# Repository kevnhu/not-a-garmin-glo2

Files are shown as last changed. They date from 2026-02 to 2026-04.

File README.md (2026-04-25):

# ForeFlight WiFi GPS

A WiFi GPS receiver for ForeFlight using ESP32, M8N GPS module, and OLED display. Built with ESP-IDF framework in pure C with FreeRTOS.

The ESP32 creates a WiFi access point and sends GPS data to ForeFlight using the GDL90 protocol over UDP. Just connect your iPad to the "ForeFlight GPS" WiFi network and ForeFlight automatically picks up the GPS data - no pairing or certification needed.

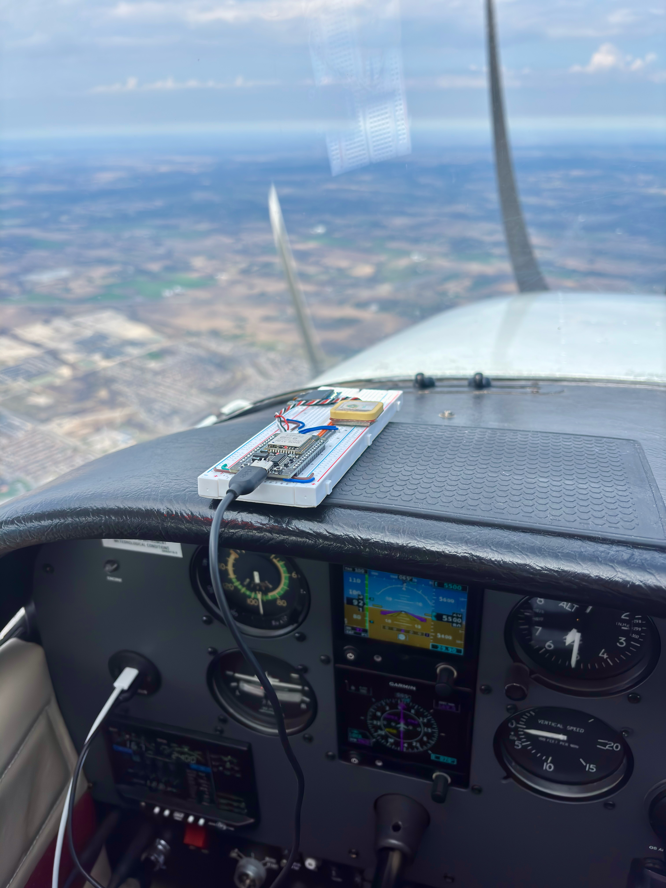
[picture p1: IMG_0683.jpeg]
ForeFlight GPS in use on a flight to Billy Bishop (CYTZ)


## Hardware Requirements

- ESP32 development board
- M8N GPS module (u-blox, 115200 baud, UBX protocol)
- 128x64 OLED display (I2C, SSD1306)
- Jumper wires
- USB cable for programming
- Battery/power source (optional, for portable use)

## Wiring Connections

### M8N GPS Module
- **GPS TX** → ESP32 **GPIO16** (RX2)
- **GPS RX** → ESP32 **GPIO17** (TX2)
- **VCC** → ESP32 **5V** pin (passes USB voltage through)
- **GND** → **GND**

### OLED Display (I2C)
- **SDA** → ESP32 **GPIO21**
- **SCL** (also labeled SCK on some modules) → ESP32 **GPIO22**
- **VCC** → ESP32 **3.3V** pin
- **GND** → **GND**

### Power Notes
- The ESP32 3.3V pin supplies 3.3V when powered via USB
- The ESP32 5V/VIN pin passes through USB voltage (~5V)
- The M8N GPS module can run on 3.3V or 5V (check your module)
- The OLED display runs on 3.3V

## Software Setup

### Prerequisites
- **Python 3.10+** (ESP-IDF v6.x requirement)
  - macOS: `brew install python@3.12`
- **cmake**: `brew install cmake`

### 1. Install ESP-IDF
Follow the official ESP-IDF installation guide:
- **macOS/Linux**: https://docs.espressif.com/projects/esp-idf/en/latest/esp32/get-started/linux-macos-setup.html
- **Windows**: https://docs.espressif.com/projects/esp-idf/en/latest/esp32/get-started/windows-setup.html

Quick install (macOS/Linux):
```bash
mkdir -p ~/esp
cd ~/esp
git clone --recursive https://github.com/espressif/esp-idf.git
cd esp-idf
./install.sh esp32
. ./export.sh
```

### 2. Build and Flash

Set up environment (run this in every new terminal):
```bash
. ~/esp/esp-idf/export.sh
```

Navigate to your project directory:
```bash
cd "/Users/kevin/Desktop/EFB Bluetooth GPS"
```

Build the project:
```bash
idf.py build
```

Flash to ESP32:
```bash
idf.py -p /dev/cu.usbserial-* flash
```
(Replace `/dev/cu.usbserial-*` with your actual port. Use `ls /dev/cu.*` to find it on macOS)

Monitor serial output:
```bash
idf.py -p /dev/cu.usbserial-* monitor
```

Or build + flash + monitor in one command:
```bash
idf.py -p /dev/cu.usbserial-* flash monitor
```

## OLED Display

The OLED display shows real-time GPS and WiFi status using a built-in 5x7 pixel font:
- **Line 1**: "ForeFlight GPS" title
- **Line 2**: WiFi connection status (Connected / Waiting...)
- **Line 3**: GPS fix status (FIX / Searching)
- **Line 4**: Number of satellites
- **Line 5**: Altitude (meters)
- **Line 6**: Latitude
- **Line 7**: Longitude

## How It Works

1. **GPS**: The M8N module communicates at 115200 baud using UBX protocol natively. At startup, the firmware sends a UBX CFG-PRT command to switch the module's output to NMEA 0183 format, then parses NMEA sentences to extract position data.
2. **WiFi**: The ESP32 creates a WiFi access point ("ForeFlight GPS"). When an iPad connects, the firmware broadcasts GDL90 protocol messages over UDP port 4000. ForeFlight automatically detects the GPS data - no pairing or certification needed.
3. **GDL90**: The firmware encodes GPS position into GDL90 messages (Heartbeat, Ownship Report, Geometric Altitude, ForeFlight ID) with proper CRC-16 and byte stuffing, sent once per second.
4. **Display**: A separate FreeRTOS task updates the OLED every 2 seconds with parsed GPS data.

## Troubleshooting

### Build Errors
- Make sure ESP-IDF environment is sourced: `. ~/esp/esp-idf/export.sh`
- Check ESP-IDF version: `idf.py --version` (v6.1+ tested)
- Ensure Python 3.10+ is installed: `python3 --version`
- Ensure cmake is installed: `cmake --version`
- Clean build: `idf.py fullclean` then `idf.py build`

### No GPS Fix
- Ensure you're outdoors or near a window
- GPS needs clear view of sky
- First fix can take 1-2 minutes (cold start)
- Check wiring connections
- Verify GPS module has power (LED should blink)
- Monitor serial output: `idf.py monitor` to see NMEA sentences

### WiFi Won't Connect
- Make sure ESP32 is powered on
- Check serial monitor for "WiFi AP started" message
- Look for "ForeFlight GPS" network in iPad WiFi settings
- Try toggling WiFi off/on on your iPad
- Restart ESP32

### No Data in ForeFlight
- Check OLED display shows satellites and fix
- Verify iPad is connected to "ForeFlight GPS" WiFi network
- Check serial monitor for "WiFi client connected" message
- In ForeFlight, go to More > Devices to check GPS status
- Ensure you have a GPS fix (OLED shows "FIX")

### OLED Display Not Working
- The firmware scans the I2C bus at startup and logs found addresses
- Check serial monitor for "I2C device found at address 0x3C"
- If your display uses 0x3D, modify `OLED_ADDRESS` in main/main.c
- Verify wiring: SDA → GPIO21, SCL → GPIO22
- Check power to OLED (3.3V)

## Power Options

### USB Power
- Connect ESP32 to USB power bank or USB charger

### Battery Power
- Use 3.7V LiPo battery with ESP32 battery connector
- Or use 5V power bank connected to ESP32 USB port

### Estimated Battery Life
- USB power bank (10,000mAh): ~24+ hours

## Configuration

### Change WiFi Network Name
Edit in main/main.c:
```c
#define WIFI_SSID "ForeFlight GPS"
```

### Adjust GPS Baud Rate
Edit in main/main.c (must match your GPS module):
```c
#define GPS_BAUD_RATE 115200
```

### Change Pin Assignments
Edit in main/main.c:
```c
#define GPS_RX_PIN 16
#define GPS_TX_PIN 17
#define I2C_MASTER_SDA_IO 21
#define I2C_MASTER_SCL_IO 22
```

### Change Display Update Rate
Modify in display_task() function (milliseconds):
```c
vTaskDelay(pdMS_TO_TICKS(2000));  // 2000 = 2 seconds
```

## Technical Specifications

- **Framework**: ESP-IDF v6.1 (Pure C with FreeRTOS)
- **Connectivity**: WiFi SoftAP (open, channel 6)
- **Protocol**: GDL90 (Garmin DO-267A) over UDP port 4000
  - Heartbeat (0x00): Sent every second
  - Ownship Report (0x0A): GPS position, altitude, speed, track
  - Geometric Altitude (0x0B): GPS altitude in 5-foot increments
  - ForeFlight ID (0x65): Device identification
- **GPS Module**: u-blox M8N at 115200 baud
- **GPS Output Format**: NMEA 0183 (converted from UBX at startup)
- **Update Rate**: 10Hz (M8N default)
- **Accuracy**: ~2.5m CEP (M8N specification)
- **OLED**: SSD1306 128x64, I2C at 0x3C, built-in 5x7 font
- **RTOS Tasks**:
  - GPS task (priority 5): Reads UART, parses NMEA
  - GDL90 task (priority 4): Encodes and broadcasts GDL90 messages
  - Display task (priority 3): Updates OLED every 2 seconds

## Project Structure

```
EFB Bluetooth GPS/
├── CMakeLists.txt              # Root build configuration
├── main/
│   ├── CMakeLists.txt          # Component build config
│   ├── Kconfig.projbuild       # Configuration menu
│   └── main.c                  # Main application (C code)
├── enclosure/
│   └── enclosure.scad          # Parametric 3D-printable case (OpenSCAD)
├── sdkconfig                   # ESP-IDF build configuration
└── README.md                   # This file
```

## Development Tips

### View Serial Output
```bash
idf.py -p /dev/cu.usbserial-* monitor
```

### Clean Build
```bash
idf.py fullclean
idf.py build
```

### Erase Flash Completely
```bash
idf.py erase-flash
idf.py flash
```

### Check Code Size
```bash
idf.py size
```

## License

Free to use and modify for personal projects.

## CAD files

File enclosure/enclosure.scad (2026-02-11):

/*
 * ForeFlight WiFi GPS Enclosure
 *
 * Two-part case (base + lid) joined with 4x M3 bolts.
 * M3 bolts pass through lid (3.3mm) and self-thread into base (2.9mm).
 * Solid corner gussets merge bolt bosses with walls for maximum strength.
 *
 * Components:
 *   ESP32 (55x30mm) - double-sided tape to base floor
 *   M8N GPS (25x25mm) - glued into lid lip, antenna pokes through 20x20 hole
 *   OLED (25x28mm) - mounted in lid rotated 90 degrees, visible through window
 *
 * Print both parts open-side-up. Flip lid when assembling.
 * Material: PETG recommended (cockpit heat resistance)
 * Print settings: 0.2mm layers, 3 perimeters, 20% infill
 */

// ===================== PARAMETERS =====================

/* [Shell] */
wall     = 2;        // Wall/floor/ceiling thickness (mm)
round_r  = 3;        // Exterior corner rounding radius
chamfer  = 1.5;      // 45-degree chamfer on outer edges

/* [Interior Cavity] */
cav_l    = 70;       // Interior length (X)
cav_w    = 44;       // Interior width (Y)
base_d   = 12;       // Base interior depth
lid_d    = 8;        // Lid interior depth

/* [ESP32 Board] */
esp_l    = 55;       // Board length
esp_w    = 30;       // Board width

/* [M8N GPS Module] */
gps_s    = 25;       // Module size (25x25)
gps_hole = 20;       // Antenna opening (20x20)

/* [OLED Display - rotated 90 degrees] */
oled_pcb_l  = 28;    // PCB length (before rotation)
oled_pcb_w  = 25;    // PCB width (before rotation)
oled_l   = 25;       // Module extent along X (after rotation)
oled_w   = 28;       // Module extent along Y (after rotation)
oled_vis_l = 13;     // Visible screen area along X
oled_vis_w = 25;     // Visible screen area along Y

/* [M3 Fasteners] */
thd_d    = 2.9;      // Self-threading hole diameter (base only)
clr_d    = 3.3;      // Clearance through-hole diameter (lid only)
boss_d   = 7;        // Boss outer diameter
boss_in  = 2;        // Boss center inset from interior wall
fillet_r = 3;        // Inner corner fillet radius

/* [USB Port Cutout] */
usb_w    = 12;       // Port width
usb_h    = 7;        // Port height

/* [Vertical Ventilation Slots] */
vent_n   = 10;       // Number of slots per side
vent_w   = 2;        // Slot width (along wall length)
vent_gap = 2.5;      // Gap between slots
vent_top = 3;        // Solid material above vents (enclosed top)

/* [Resolution] */
$fn      = 48;

// ===================== DERIVED VALUES =====================

ext_l    = cav_l + 2 * wall;
ext_w    = cav_w + 2 * wall;
base_h   = base_d + wall;
lid_h    = lid_d + wall;
gps_lip  = (gps_s - gps_hole) / 2;

// Bolt positions (exterior coordinates)
bolt_edge = wall + boss_in;
bolts = [
    [bolt_edge,         bolt_edge],
    [ext_l - bolt_edge, bolt_edge],
    [bolt_edge,         ext_w - bolt_edge],
    [ext_l - bolt_edge, ext_w - bolt_edge]
];

// Corner gusset size (from edge to far side of boss)
gusset = bolt_edge + boss_d / 2;

// Component positions (interior coordinates)
oled_x = (cav_l / 2 - oled_l) / 2;
oled_y = (cav_w - oled_w) / 2;
gps_x  = cav_l / 2 + (cav_l / 2 - gps_s) / 2;
gps_y  = (cav_w - gps_s) / 2;

// Vent slot layout (centered on long walls)
vent_total = vent_n * vent_w + (vent_n - 1) * vent_gap;
vent_start = (ext_l - vent_total) / 2;
vent_h     = base_d - vent_top;  // Slot height (floor to top minus margin)

// ===================== MODULES =====================

// Rounded rectangle extrusion
module rrect(l, w, h, r) {
    r2 = min(r, min(l, w) / 2 - 0.01);
    hull() {
        translate([r2,     r2,     0]) cylinder(r = r2, h = h);
        translate([l - r2, r2,     0]) cylinder(r = r2, h = h);
        translate([r2,     w - r2, 0]) cylinder(r = r2, h = h);
        translate([l - r2, w - r2, 0]) cylinder(r = r2, h = h);
    }
}

// 45-degree chamfer subtracted from outer edge (true taper via hull)
module chamfer_edge(l, w, r, ch, z_pos) {
    translate([0, 0, z_pos])
        difference() {
            translate([-1, -1, -0.01])
                cube([l + 2, w + 2, ch + 0.02]);
            hull() {
                // Smaller footprint at z=0 (the exposed edge)
                translate([ch, ch, 0])
                    rrect(l - 2 * ch, w - 2 * ch, 0.01, max(0.5, r - ch));
                // Full footprint at z=ch (merges flush with body)
                translate([0, 0, ch])
                    rrect(l, w, 0.01, r);
            }
        }
}

// Fillet cutters: round the sharp inner edge of each corner gusset
// For each corner, subtracts a (square minus quarter-circle) wedge
module gusset_fillets(r, h) {
    fh = h - wall;  // only cut cavity depth, preserve floor/ceiling
    for (b = bolts) {
        ix = (b[0] < ext_l / 2) ? gusset : ext_l - gusset;
        iy = (b[1] < ext_w / 2) ? gusset : ext_w - gusset;
        dx = (b[0] < ext_l / 2) ? -1 : 1;
        dy = (b[1] < ext_w / 2) ? -1 : 1;
        translate([ix + min(0, dx) * r, iy + min(0, dy) * r, wall])
            difference() {
                cube([r, r, fh + 0.1]);
                translate([(dx > 0) ? r : 0, (dy > 0) ? r : 0, -0.1])
                    cylinder(r = r, h = fh + 0.3);
            }
    }
}

// ===================== BASE =====================
// Bosses are added AFTER the cavity is cut, so they stay solid.
// Only the bolt hole (2.9mm) is drilled through them.

module base() {
    inner_r = max(1, round_r - wall);

    difference() {
        union() {
            // Step 1: Shell with cavity already removed
            difference() {
                rrect(ext_l, ext_w, base_h, round_r);

                translate([wall, wall, wall])
                    rrect(cav_l, cav_w, base_d + 1, inner_r);
            }

            // Step 2: Solid corner gussets (boss merged with walls)
            // Added AFTER cavity cut so they remain fully solid
            for (b = bolts) {
                gx = (b[0] < ext_l / 2) ? 0 : ext_l - gusset;
                gy = (b[1] < ext_w / 2) ? 0 : ext_w - gusset;
                intersection() {
                    rrect(ext_l, ext_w, base_h, round_r);
                    translate([gx, gy, 0])
                        cube([gusset, gusset, base_h]);
                }
            }

        }

        // M3 self-threading holes (2.9mm) through solid gussets
        for (b = bolts)
            translate([b[0], b[1], -0.1])
                cylinder(d = thd_d, h = base_h + 0.2);

        // USB port cutout (left wall, centered on Y)
        translate([-0.1, (ext_w - usb_w) / 2, wall + 1])
            cube([wall + 0.2, usb_w, usb_h]);

        // Vertical vent slots on FRONT wall (Y=0)
        // Run from floor (z=wall) up, enclosed at top with vent_top mm
        for (i = [0 : vent_n - 1])
            translate([
                vent_start + i * (vent_w + vent_gap),
                -0.1,
                wall
            ])
                cube([vent_w, wall + 0.2, vent_h]);

        // Vertical vent slots on BACK wall (Y=ext_w)
        for (i = [0 : vent_n - 1])
            translate([
                vent_start + i * (vent_w + vent_gap),
                ext_w - wall - 0.1,
                wall
            ])
                cube([vent_w, wall + 0.2, vent_h]);

        // Round inner corners of gussets (3mm fillet)
        gusset_fillets(fillet_r, base_h);

        // 45-degree chamfer on bottom outer edge
        chamfer_edge(ext_l, ext_w, round_r, chamfer, -0.01);
    }
}

// ===================== LID =====================
// Bosses added after cavity cut to stay solid.
// 3.3mm clearance holes only.

module lid() {
    inner_r = max(1, round_r - wall);
    shelf_h = 1.5;
    oled_lip = 1.5;

    difference() {
        union() {
            // Step 1: Shell with cavity removed
            difference() {
                rrect(ext_l, ext_w, lid_h, round_r);

                translate([wall, wall, wall])
                    rrect(cav_l, cav_w, lid_d + 1, inner_r);
            }

            // Step 2: Solid corner gussets (boss merged with walls)
            for (b = bolts) {
                gx = (b[0] < ext_l / 2) ? 0 : ext_l - gusset;
                gy = (b[1] < ext_w / 2) ? 0 : ext_w - gusset;
                intersection() {
                    rrect(ext_l, ext_w, lid_h, round_r);
                    translate([gx, gy, 0])
                        cube([gusset, gusset, lid_h]);
                }
            }

        }

        // M3 clearance through-holes (3.3mm)
        for (b = bolts)
            translate([b[0], b[1], -0.1])
                cylinder(d = clr_d, h = lid_h + 0.2);

        // GPS antenna opening: 20x20mm through ceiling
        translate([
            wall + gps_x + gps_lip,
            wall + gps_y + gps_lip,
            -0.1
        ])
            cube([gps_hole, gps_hole, wall + 0.2]);
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

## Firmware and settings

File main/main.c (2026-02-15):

/*
 * ForeFlight WiFi GPS - ESP-IDF Version
 * ESP32 + M8N GPS + OLED Display
 *
 * Sends GPS data to ForeFlight via WiFi using GDL90 protocol.
 * ESP32 creates a WiFi access point, iPad connects to it,
 * and ForeFlight automatically receives GPS data via UDP broadcast.
 *
 * Connections:
 * M8N GPS:
 *   - GPS TX -> ESP32 GPIO16 (RX2)
 *   - GPS RX -> ESP32 GPIO17 (TX2)
 *   - VCC -> 3.3V or 5V
 *   - GND -> GND
 *
 * OLED Display (I2C):
 *   - SDA -> GPIO21
 *   - SCL -> GPIO22
 *   - VCC -> 3.3V
 *   - GND -> GND
 */

#include <stdio.h>
#include <string.h>
#include <stdlib.h>
#include "freertos/FreeRTOS.h"
#include "freertos/task.h"
#include "driver/uart.h"
#include "driver/gpio.h"
#include "driver/i2c.h"
#include "esp_log.h"
#include "esp_wifi.h"
#include "esp_event.h"
#include "esp_netif.h"
#include "nvs_flash.h"
#include "lwip/sockets.h"

// Configuration
#define GPS_UART_NUM        UART_NUM_2
#define GPS_RX_PIN          16
#define GPS_TX_PIN          17
#define GPS_BAUD_RATE       115200
#define GPS_BUF_SIZE        1024

#define I2C_MASTER_SCL_IO   22
#define I2C_MASTER_SDA_IO   21
#define I2C_MASTER_NUM      I2C_NUM_0
#define I2C_MASTER_FREQ_HZ  100000
#define OLED_ADDRESS        0x3C

#define WIFI_SSID           "ForeFlight GPS"
#define WIFI_CHANNEL        6
#define WIFI_MAX_CONN       4

#define GDL90_PORT          4000
#define GDL90_FLAG          0x7E
#define GDL90_ESCAPE        0x7D

// OLED Commands
#define OLED_CMD_DISPLAY_OFF    0xAE
#define OLED_CMD_DISPLAY_ON     0xAF
#define OLED_CMD_SET_CONTRAST   0x81
#define OLED_CMD_DISPLAY_NORMAL 0xA6
#define OLED_CMD_SET_MUX_RATIO  0xA8
#define OLED_CMD_SET_DISPLAY_OFFSET 0xD3
#define OLED_CMD_SET_START_LINE 0x40
#define OLED_CMD_SET_SEGMENT_REMAP 0xA1
#define OLED_CMD_SET_COM_SCAN_DEC 0xC8
#define OLED_CMD_SET_COM_PINS   0xDA
#define OLED_CMD_SET_PRECHARGE  0xD9
#define OLED_CMD_SET_VCOM_DETECT 0xDB
#define OLED_CMD_CHARGE_PUMP    0x8D
#define OLED_CMD_DEACTIVATE_SCROLL 0x2E

static const char *TAG = "GPS";

// GPS data structure
typedef struct {
    int satellites;
    bool gps_fixed;
    char latitude_str[20];
    char longitude_str[20];
    char altitude_str[16];
    double latitude;      // decimal degrees (+N, -S)
    double longitude;     // decimal degrees (+E, -W)
    double altitude_m;    // meters
    double speed_kt;      // ground speed in knots
    double track_deg;     // true track in degrees
} gps_data_t;

static gps_data_t gps_data = {0};
static int wifi_clients = 0;
static int udp_sock = -1;

// ==================== I2C / OLED Functions ====================

static esp_err_t i2c_master_init(void)
{
    i2c_config_t conf = {
        .mode = I2C_MODE_MASTER,
        .sda_io_num = I2C_MASTER_SDA_IO,
        .scl_io_num = I2C_MASTER_SCL_IO,
        .sda_pullup_en = GPIO_PULLUP_ENABLE,
        .scl_pullup_en = GPIO_PULLUP_ENABLE,
        .master.clk_speed = I2C_MASTER_FREQ_HZ,
    };

    esp_err_t err = i2c_param_config(I2C_MASTER_NUM, &conf);
    if (err != ESP_OK) return err;

    return i2c_driver_install(I2C_MASTER_NUM, conf.mode, 0, 0, 0);
}

static esp_err_t oled_write_cmd(uint8_t cmd)
{
    i2c_cmd_handle_t i2c_cmd = i2c_cmd_link_create();
    i2c_master_start(i2c_cmd);
    i2c_master_write_byte(i2c_cmd, (OLED_ADDRESS << 1) | I2C_MASTER_WRITE, true);
    i2c_master_write_byte(i2c_cmd, 0x00, true);
    i2c_master_write_byte(i2c_cmd, cmd, true);
    i2c_master_stop(i2c_cmd);
    esp_err_t ret = i2c_master_cmd_begin(I2C_MASTER_NUM, i2c_cmd, pdMS_TO_TICKS(1000));
    i2c_cmd_link_delete(i2c_cmd);
    return ret;
}

static esp_err_t oled_write_data(uint8_t *data, size_t len)
{
    i2c_cmd_handle_t i2c_cmd = i2c_cmd_link_create();
    i2c_master_start(i2c_cmd);
    i2c_master_write_byte(i2c_cmd, (OLED_ADDRESS << 1) | I2C_MASTER_WRITE, true);
    i2c_master_write_byte(i2c_cmd, 0x40, true);
    i2c_master_write(i2c_cmd, data, len, true);
    i2c_master_stop(i2c_cmd);
    esp_err_t ret = i2c_master_cmd_begin(I2C_MASTER_NUM, i2c_cmd, pdMS_TO_TICKS(1000));
    i2c_cmd_link_delete(i2c_cmd);
    return ret;
}

static void oled_init(void)
{
    vTaskDelay(pdMS_TO_TICKS(100));

    oled_write_cmd(OLED_CMD_DISPLAY_OFF);
    oled_write_cmd(OLED_CMD_SET_MUX_RATIO);
    oled_write_cmd(0x3F);
    oled_write_cmd(OLED_CMD_SET_DISPLAY_OFFSET);
    oled_write_cmd(0x00);
    oled_write_cmd(OLED_CMD_SET_START_LINE | 0x00);
    oled_write_cmd(OLED_CMD_SET_SEGMENT_REMAP);
    oled_write_cmd(OLED_CMD_SET_COM_SCAN_DEC);
    oled_write_cmd(OLED_CMD_SET_COM_PINS);
    oled_write_cmd(0x12);
    oled_write_cmd(OLED_CMD_SET_CONTRAST);
    oled_write_cmd(0xCF);
    oled_write_cmd(OLED_CMD_DISPLAY_NORMAL);
    oled_write_cmd(OLED_CMD_SET_PRECHARGE);
    oled_write_cmd(0xF1);
    oled_write_cmd(OLED_CMD_SET_VCOM_DETECT);
    oled_write_cmd(0x40);
    oled_write_cmd(OLED_CMD_CHARGE_PUMP);
    oled_write_cmd(0x14);
    oled_write_cmd(OLED_CMD_DEACTIVATE_SCROLL);
    oled_write_cmd(OLED_CMD_DISPLAY_ON);

    for (int page = 0; page < 8; page++) {
        oled_write_cmd(0xB0 + page);
        oled_write_cmd(0x00);
        oled_write_cmd(0x10);
        uint8_t zeros[128] = {0};
        oled_write_data(zeros, 128);
    }
}

// 5x7 font table (ASCII 32-126)
static const uint8_t font5x7[][5] = {
    {0x00,0x00,0x00,0x00,0x00}, // space
    {0x00,0x00,0x5F,0x00,0x00}, // !
    {0x00,0x07,0x00,0x07,0x00}, // "
    {0x14,0x7F,0x14,0x7F,0x14}, // #
    {0x24,0x2A,0x7F,0x2A,0x12}, // $
    {0x23,0x13,0x08,0x64,0x62}, // %
    {0x36,0x49,0x55,0x22,0x50}, // &
    {0x00,0x05,0x03,0x00,0x00}, // '
    {0x00,0x1C,0x22,0x41,0x00}, // (
    {0x00,0x41,0x22,0x1C,0x00}, // )
    {0x08,0x2A,0x1C,0x2A,0x08}, // *
    {0x08,0x08,0x3E,0x08,0x08}, // +
    {0x00,0x50,0x30,0x00,0x00}, // ,
    {0x08,0x08,0x08,0x08,0x08}, // -
    {0x00,0x60,0x60,0x00,0x00}, // .
    {0x20,0x10,0x08,0x04,0x02}, // /
    {0x3E,0x51,0x49,0x45,0x3E}, // 0
    {0x00,0x42,0x7F,0x40,0x00}, // 1
    {0x42,0x61,0x51,0x49,0x46}, // 2
    {0x21,0x41,0x45,0x4B,0x31}, // 3
    {0x18,0x14,0x12,0x7F,0x10}, // 4
    {0x27,0x45,0x45,0x45,0x39}, // 5
    {0x3C,0x4A,0x49,0x49,0x30}, // 6
    {0x01,0x71,0x09,0x05,0x03}, // 7
    {0x36,0x49,0x49,0x49,0x36}, // 8
    {0x06,0x49,0x49,0x29,0x1E}, // 9
    {0x00,0x36,0x36,0x00,0x00}, // :
    {0x00,0x56,0x36,0x00,0x00}, // ;
    {0x00,0x08,0x14,0x22,0x41}, // <
    {0x14,0x14,0x14,0x14,0x14}, // =
    {0x41,0x22,0x14,0x08,0x00}, // >
    {0x02,0x01,0x51,0x09,0x06}, // ?
    {0x32,0x49,0x79,0x41,0x3E}, // @
    {0x7E,0x11,0x11,0x11,0x7E}, // A
    {0x7F,0x49,0x49,0x49,0x36}, // B
    {0x3E,0x41,0x41,0x41,0x22}, // C
    {0x7F,0x41,0x41,0x22,0x1C}, // D
    {0x7F,0x49,0x49,0x49,0x41}, // E
    {0x7F,0x09,0x09,0x01,0x01}, // F
    {0x3E,0x41,0x41,0x51,0x32}, // G
    {0x7F,0x08,0x08,0x08,0x7F}, // H
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
    {0x02,0x04,0x08,0x10,0x20}, // backslash
    {0x41,0x41,0x7F,0x00,0x00}, // ]
    {0x04,0x02,0x01,0x02,0x04}, // ^
    {0x40,0x40,0x40,0x40,0x40}, // _
    {0x00,0x01,0x02,0x04,0x00}, // `
    {0x20,0x54,0x54,0x54,0x78}, // a
    {0x7F,0x48,0x44,0x44,0x38}, // b
    {0x38,0x44,0x44,0x44,0x20}, // c
    {0x38,0x44,0x44,0x48,0x7F}, // d
    {0x38,0x54,0x54,0x54,0x18}, // e
    {0x08,0x7E,0x09,0x01,0x02}, // f
    {0x08,0x54,0x54,0x54,0x3C}, // g
    {0x7F,0x08,0x04,0x04,0x78}, // h
    {0x00,0x44,0x7D,0x40,0x00}, // i
    {0x20,0x40,0x44,0x3D,0x00}, // j
    {0x00,0x7F,0x10,0x28,0x44}, // k
    {0x00,0x41,0x7F,0x40,0x00}, // l
    {0x7C,0x04,0x18,0x04,0x78}, // m
    {0x7C,0x08,0x04,0x04,0x78}, // n
    {0x38,0x44,0x44,0x44,0x38}, // o
    {0x7C,0x14,0x14,0x14,0x08}, // p
    {0x08,0x14,0x14,0x18,0x7C}, // q
    {0x7C,0x08,0x04,0x04,0x08}, // r
    {0x48,0x54,0x54,0x54,0x20}, // s
    {0x04,0x3F,0x44,0x40,0x20}, // t
    {0x3C,0x40,0x40,0x20,0x7C}, // u
    {0x1C,0x20,0x40,0x20,0x1C}, // v
    {0x3C,0x40,0x30,0x40,0x3C}, // w
    {0x44,0x28,0x10,0x28,0x44}, // x
    {0x0C,0x50,0x50,0x50,0x3C}, // y
    {0x44,0x64,0x54,0x4C,0x44}, // z
    {0x00,0x08,0x36,0x41,0x00}, // {
    {0x00,0x00,0x7F,0x00,0x00}, // |
    {0x00,0x41,0x36,0x08,0x00}, // }
    {0x08,0x08,0x2A,0x1C,0x08}, // ~
};

static void oled_draw_text(int page, int col, const char* text)
{
    oled_write_cmd(0xB0 + page);
    oled_write_cmd(0x00 + (col & 0x0F));
    oled_write_cmd(0x10 + ((col >> 4) & 0x0F));

    while (*text) {
        int idx = *text - 32;
        if (idx >= 0 && idx < 95) {
            oled_write_data((uint8_t *)font5x7[idx], 5);
            uint8_t space = 0x00;
            oled_write_data(&space, 1);
        }
        text++;
    }
}

static void oled_update_display(void)
{
    for (int page = 0; page < 8; page++) {
        oled_write_cmd(0xB0 + page);
        oled_write_cmd(0x00);
        oled_write_cmd(0x10);
        uint8_t zeros[128] = {0};
        oled_write_data(zeros, 128);
    }

    char line[32];

    oled_draw_text(0, 0, "ForeFlight GPS");

    snprintf(line, sizeof(line), "WiFi: %s", wifi_clients > 0 ? "Connected" : "Waiting...");
    oled_draw_text(1, 0, line);

    snprintf(line, sizeof(line), "GPS: %s", gps_data.gps_fixed ? "FIX" : "Searching");
    oled_draw_text(2, 0, line);

    snprintf(line, sizeof(line), "Sats: %d", gps_data.satellites);
    oled_draw_text(3, 0, line);

    if (gps_data.altitude_str[0]) {
        snprintf(line, sizeof(line), "Alt: %sm", gps_data.altitude_str);
        oled_draw_text(4, 0, line);
    }

    if (gps_data.latitude_str[0]) {
        snprintf(line, sizeof(line), "Lat: %s", gps_data.latitude_str);
        oled_draw_text(5, 0, line);
    }

    if (gps_data.longitude_str[0]) {
        snprintf(line, sizeof(line), "Lon: %s", gps_data.longitude_str);
        oled_draw_text(6, 0, line);
    }
}

// ==================== NMEA Parser ====================

static double nmea_to_dd(const char *coord, char dir)
{
    if (!coord || !coord[0]) return 0.0;
    double raw = atof(coord);
    int deg = (int)(raw / 100);
    double min = raw - deg * 100;
    double dd = deg + min / 60.0;
    if (dir == 'S' || dir == 'W') dd = -dd;
    return dd;
}

static void parse_nmea(const char *sentence)
{
    if (strncmp(sentence, "$GPGGA", 6) == 0 || strncmp(sentence, "$GNGGA", 6) == 0) {
        char *buf = strdup(sentence);
        char *token = strtok(buf, ",");
        int field = 0;
        char lat[16] = "", lon[16] = "";
        char lat_d = 'N', lon_d = 'E';

        while (token != NULL) {
            field++;
            switch (field) {
                case 3: strncpy(lat, token, sizeof(lat) - 1); break;
                case 4: if (token[0]) lat_d = token[0]; break;
                case 5: strncpy(lon, token, sizeof(lon) - 1); break;
                case 6: if (token[0]) lon_d = token[0]; break;
                case 7: gps_data.gps_fixed = (atoi(token) > 0); break;
                case 8: gps_data.satellites = atoi(token); break;
                case 10:
                    strncpy(gps_data.altitude_str, token, sizeof(gps_data.altitude_str) - 1);
                    gps_data.altitude_m = atof(token);
                    break;
            }
            token = strtok(NULL, ",");
        }

        if (lat[0]) {
            gps_data.latitude = nmea_to_dd(lat, lat_d);
            snprintf(gps_data.latitude_str, sizeof(gps_data.latitude_str), "%s%c", lat, lat_d);
        }
        if (lon[0]) {
            gps_data.longitude = nmea_to_dd(lon, lon_d);
            snprintf(gps_data.longitude_str, sizeof(gps_data.longitude_str), "%s%c", lon, lon_d);
        }

        free(buf);
    }
    else if (strncmp(sentence, "$GPRMC", 6) == 0 || strncmp(sentence, "$GNRMC", 6) == 0) {
        char *buf = strdup(sentence);
        char *token = strtok(buf, ",");
        int field = 0;

        while (token != NULL) {
            field++;
            switch (field) {
                case 8: gps_data.speed_kt = atof(token); break;
                case 9: gps_data.track_deg = atof(token); break;
            }
            token = strtok(NULL, ",");
        }

        free(buf);
    }
}

// ==================== GPS UBX Configuration ====================

static void gps_send_ubx(const uint8_t *msg, size_t len)
{
    uart_write_bytes(GPS_UART_NUM, (const char *)msg, len);
    uart_wait_tx_done(GPS_UART_NUM, pdMS_TO_TICKS(100));
}

static void gps_configure(void)
{
    ESP_LOGI(TAG, "Configuring GPS for NMEA output and WAAS/SBAS...");

    // CFG-PRT: Configure UART for NMEA output
    uint8_t cfg_prt[] = {
        0xB5, 0x62, 0x06, 0x00, 0x14, 0x00,
        0x01, 0x00, 0x00, 0x00,
        0xD0, 0x08, 0x00, 0x00,
        0x00, 0xC2, 0x01, 0x00,
        0x07, 0x00, 0x02, 0x00,
        0x00, 0x00, 0x00, 0x00,
        0x00, 0x00
    };
    uint8_t ck_a = 0, ck_b = 0;
    for (int i = 2; i < (int)sizeof(cfg_prt) - 2; i++) {
        ck_a += cfg_prt[i];
        ck_b += ck_a;
    }
    cfg_prt[sizeof(cfg_prt) - 2] = ck_a;
    cfg_prt[sizeof(cfg_prt) - 1] = ck_b;
    gps_send_ubx(cfg_prt, sizeof(cfg_prt));
    vTaskDelay(pdMS_TO_TICKS(200));

    // CFG-SBAS: Enable WAAS/SBAS for accuracy improvement (~1m)
    uint8_t cfg_sbas[] = {
        0xB5, 0x62, 0x06, 0x16, 0x08, 0x00,
        0x01,                   // Mode: 1 = enabled
        0x07,                   // Usage: 7 = use for GPS correction
        0x03,                   // maxSBAS: 3 satellites
        0x00,                   // flags
        0x00, 0x00, 0x00, 0x00, // padding
        0x00, 0x00              // checksum (will be calculated)
    };
    ck_a = 0;
    ck_b = 0;
    for (int i = 2; i < (int)sizeof(cfg_sbas) - 2; i++) {
        ck_a += cfg_sbas[i];
        ck_b += ck_a;
    }
    cfg_sbas[sizeof(cfg_sbas) - 2] = ck_a;
    cfg_sbas[sizeof(cfg_sbas) - 1] = ck_b;
    gps_send_ubx(cfg_sbas, sizeof(cfg_sbas));
    vTaskDelay(pdMS_TO_TICKS(200));

    uart_flush(GPS_UART_NUM);
    ESP_LOGI(TAG, "GPS configured for NMEA output with WAAS/SBAS enabled");
}

// ==================== GDL90 Protocol ====================

static uint16_t gdl90_crc_table[256];

static void gdl90_crc_init(void)
{
    for (int i = 0; i < 256; i++) {
        uint16_t crc = (uint16_t)(i << 8);
        for (int j = 0; j < 8; j++) {
            crc = (crc & 0x8000) ? ((crc << 1) ^ 0x1021) : (crc << 1);
        }
        gdl90_crc_table[i] = crc;
    }
}

static uint16_t gdl90_crc(const uint8_t *data, size_t len)
{
    uint16_t crc = 0;
    for (size_t i = 0; i < len; i++) {
        crc = gdl90_crc_table[crc >> 8] ^ (crc << 8) ^ data[i];
    }
    return crc;
}

static size_t gdl90_frame(const uint8_t *msg, size_t msg_len, uint8_t *out)
{
    uint16_t crc = gdl90_crc(msg, msg_len);
    size_t idx = 0;

    out[idx++] = GDL90_FLAG;

    // Byte-stuff message data
    for (size_t i = 0; i < msg_len; i++) {
        if (msg[i] == GDL90_FLAG || msg[i] == GDL90_ESCAPE) {
            out[idx++] = GDL90_ESCAPE;
            out[idx++] = msg[i] ^ 0x20;
        } else {
            out[idx++] = msg[i];
        }
    }

    // CRC low byte (byte-stuffed)
    uint8_t crc_lo = crc & 0xFF;
    if (crc_lo == GDL90_FLAG || crc_lo == GDL90_ESCAPE) {
        out[idx++] = GDL90_ESCAPE;
        out[idx++] = crc_lo ^ 0x20;
    } else {
        out[idx++] = crc_lo;
    }

    // CRC high byte (byte-stuffed)
    uint8_t crc_hi = (crc >> 8) & 0xFF;
    if (crc_hi == GDL90_FLAG || crc_hi == GDL90_ESCAPE) {
        out[idx++] = GDL90_ESCAPE;
        out[idx++] = crc_hi ^ 0x20;
    } else {
        out[idx++] = crc_hi;
    }

    out[idx++] = GDL90_FLAG;
    return idx;
}

static void gdl90_send(const uint8_t *data, size_t len)
{
    if (udp_sock < 0) return;

    struct sockaddr_in dest = {
        .sin_family = AF_INET,
        .sin_port = htons(GDL90_PORT),
    };
    inet_aton("192.168.4.255", &dest.sin_addr);

    sendto(udp_sock, data, len, 0, (struct sockaddr *)&dest, sizeof(dest));
}

// GDL90 Heartbeat (Message ID 0) - sent every second
static void gdl90_send_heartbeat(void)
{
    uint8_t msg[7] = {
        0x00,  // Message ID
        (uint8_t)(gps_data.gps_fixed ? 0x81 : 0x01),  // Status 1: GPS valid + UAT init
        0x00,  // Status 2
        0x00, 0x00,  // Timestamp
        0x00, 0x00,  // Message counts
    };
    uint8_t frame[32];
    size_t len = gdl90_frame(msg, 7, frame);
    gdl90_send(frame, len);
}

// GDL90 Ownship Report (Message ID 10) - GPS position
static void gdl90_send_ownship(void)
{
    uint8_t msg[28];
    memset(msg, 0, sizeof(msg));

    msg[0] = 0x0A;  // Message ID: Ownship Report
    msg[1] = 0x01;  // Address type: self-assigned

    // Participant address
    msg[2] = 0x00;
    msg[3] = 0x00;
    msg[4] = 0x01;

    // Latitude (24-bit signed, semicircles)
    int32_t lat_enc = (int32_t)(gps_data.latitude / 180.0 * (1 << 23));
    msg[5] = (lat_enc >> 16) & 0xFF;
    msg[6] = (lat_enc >> 8) & 0xFF;
    msg[7] = lat_enc & 0xFF;

    // Longitude (24-bit signed, semicircles)
    int32_t lon_enc = (int32_t)(gps_data.longitude / 180.0 * (1 << 23));
    msg[8] = (lon_enc >> 16) & 0xFF;
    msg[9] = (lon_enc >> 8) & 0xFF;
    msg[10] = lon_enc & 0xFF;

    // Altitude (12-bit, 25ft increments from -1000ft)
    double alt_ft = gps_data.altitude_m * 3.28084;
    int alt_enc = (int)((alt_ft + 1000.0) / 25.0);
    if (alt_enc < 0) alt_enc = 0;
    if (alt_enc > 0xFFE) alt_enc = 0xFFE;

    // Misc: airborne + true track + updated
    uint8_t misc = 0x0B;
    msg[11] = (alt_enc >> 4) & 0xFF;
    msg[12] = ((alt_enc & 0x0F) << 4) | misc;

    // NIC=8, NACp=8
    msg[13] = 0x88;

    // Horizontal velocity (12-bit, knots)
    int hvel = (int)gps_data.speed_kt;
    if (hvel > 0xFFE) hvel = 0xFFE;

    // Vertical velocity (12-bit signed, 64fpm increments) - unknown
    int vvel = 0x800;

    msg[14] = (hvel >> 4) & 0xFF;
    msg[15] = ((hvel & 0x0F) << 4) | ((vvel >> 8) & 0x0F);
    msg[16] = vvel & 0xFF;

    // Track/Heading
    msg[17] = (uint8_t)(gps_data.track_deg / 360.0 * 256.0);

    // Emitter category: light aircraft
    msg[18] = 0x01;

    // Callsign (8 bytes, space-padded)
    memcpy(msg + 19, "FFGPS   ", 8);

    // Emergency/Priority + spare
    msg[27] = 0x00;

    uint8_t frame[96];
    size_t len = gdl90_frame(msg, 28, frame);
    gdl90_send(frame, len);
}

// GDL90 Ownship Geometric Altitude (Message ID 11)
static void gdl90_send_geo_alt(void)
{
    uint8_t msg[5];
    msg[0] = 0x0B;  // Message ID

    // Geometric altitude in 5-foot increments
    double alt_ft = gps_data.altitude_m * 3.28084;
    int16_t geo_alt = (int16_t)(alt_ft / 5.0);
    msg[1] = (geo_alt >> 8) & 0xFF;
    msg[2] = geo_alt & 0xFF;

    // Vertical figure of merit (meters)
    msg[3] = 0x00;
    msg[4] = 0x0A;  // 10 meters

    uint8_t frame[32];
    size_t len = gdl90_frame(msg, 5, frame);
    gdl90_send(frame, len);
}

// ForeFlight extended ID message (Message ID 0x65)
static void gdl90_send_ff_id(void)
{
    uint8_t msg[31];
    memset(msg, 0, sizeof(msg));

    msg[0] = 0x65;  // ForeFlight message ID
    msg[1] = 0x00;  // Sub-type: device ID
    msg[2] = 0x01;  // Version

    // Device serial (8 bytes, space-padded)
    memcpy(msg + 3, "ESPGPS01", 8);

    // Device long name (16 bytes, space-padded)
    memcpy(msg + 11, "ForeFlight GPS  ", 16);

    // Capabilities (4 bytes, big-endian)
    msg[27] = 0x00;
    msg[28] = 0x00;
    msg[29] = 0x00;
    msg[30] = 0x01;  // Bit 0: WAAS GPS

    uint8_t frame[96];
    size_t len = gdl90_frame(msg, 31, frame);
    gdl90_send(frame, len);
}

// ==================== WiFi ====================

static void wifi_event_handler(void *arg, esp_event_base_t event_base,
                                int32_t event_id, void *event_data)
{
    if (event_id == WIFI_EVENT_AP_STACONNECTED) {
        wifi_clients++;
        ESP_LOGI(TAG, "WiFi client connected (total: %d)", wifi_clients);
    } else if (event_id == WIFI_EVENT_AP_STADISCONNECTED) {
        if (wifi_clients > 0) wifi_clients--;
        ESP_LOGI(TAG, "WiFi client disconnected (total: %d)", wifi_clients);
    }
}
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
void app_main(void)
{
    ESP_LOGI(TAG, "ForeFlight WiFi GPS Starting...");

    // Initialize NVS
    esp_err_t ret = nvs_flash_init();
    if (ret == ESP_ERR_NVS_NO_FREE_PAGES || ret == ESP_ERR_NVS_NEW_VERSION_FOUND) {
        ESP_ERROR_CHECK(nvs_flash_erase());
        ret = nvs_flash_init();
    }
    ESP_ERROR_CHECK(ret);

    // Initialize I2C and OLED
    ESP_LOGI(TAG, "Initializing I2C...");
    ESP_ERROR_CHECK(i2c_master_init());

    ESP_LOGI(TAG, "Scanning I2C bus...");
    for (uint8_t addr = 1; addr < 127; addr++) {
        i2c_cmd_handle_t cmd = i2c_cmd_link_create();
        i2c_master_start(cmd);
        i2c_master_write_byte(cmd, (addr << 1) | I2C_MASTER_WRITE, true);
        i2c_master_stop(cmd);
        esp_err_t err = i2c_master_cmd_begin(I2C_MASTER_NUM, cmd, pdMS_TO_TICKS(50));
        i2c_cmd_link_delete(cmd);
        if (err == ESP_OK) {
            ESP_LOGI(TAG, "I2C device found at 0x%02X", addr);
        }
    }

    ESP_LOGI(TAG, "Initializing OLED...");
    oled_init();

    // Initialize UART for GPS
    ESP_LOGI(TAG, "Initializing GPS UART...");
    uart_config_t uart_config = {
        .baud_rate = GPS_BAUD_RATE,
        .data_bits = UART_DATA_8_BITS,
        .parity = UART_PARITY_DISABLE,
        .stop_bits = UART_STOP_BITS_1,
        .flow_ctrl = UART_HW_FLOWCTRL_DISABLE,
        .source_clk = UART_SCLK_DEFAULT,
    };

    ESP_ERROR_CHECK(uart_driver_install(GPS_UART_NUM, GPS_BUF_SIZE * 2, 0, 0, NULL, 0));
    ESP_ERROR_CHECK(uart_param_config(GPS_UART_NUM, &uart_config));
    ESP_ERROR_CHECK(uart_set_pin(GPS_UART_NUM, GPS_TX_PIN, GPS_RX_PIN, UART_PIN_NO_CHANGE, UART_PIN_NO_CHANGE));

    // Configure GPS module to output NMEA
    gps_configure();

    // Initialize WiFi AP
    ESP_LOGI(TAG, "Starting WiFi AP...");
    wifi_init_ap();

    // Initialize UDP socket
    udp_init();

    // Create tasks
    xTaskCreate(gps_task, "gps_task", 4096, NULL, 5, NULL);
    xTaskCreate(gdl90_task, "gdl90_task", 4096, NULL, 4, NULL);
    xTaskCreate(display_task, "display_task", 4096, NULL, 3, NULL);

    ESP_LOGI(TAG, "System ready! Connect iPad to WiFi: %s", WIFI_SSID);
}

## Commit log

2026-02-08 Switch to BLE with Nordic UART Service, fix GPS and OLED
    - Replace Classic Bluetooth SPP with BLE NUS for iOS compatibility
    (iOS blocks non-MFi Classic BT SPP devices)
    - Fix GPS baud rate to 115200 to match M8N module
    - Add UBX CFG-PRT command to switch GPS from UBX to NMEA output
    - Add 5x7 font table and text rendering for OLED display
    - OLED now shows: BT status, GPS fix, satellites, altitude, lat/lon
    - Add I2C bus scan at startup for OLED debugging
    - Update sdkconfig for BLE-only mode (GATTS enabled, Classic BT disabled)
    - Rewrite README with current project state and learnings
    [main.c]
2026-02-08 Switch from BLE to WiFi AP with GDL90 protocol for ForeFlight
    - Replace BLE Nordic UART Service with WiFi access point + UDP
    - Implement GDL90 protocol (heartbeat, ownship report, geo altitude)
    - Add ForeFlight extended ID message (0x65) for device identification
    - Add GDL90 CRC-16 (CRC-CCITT) with proper computation per spec
    - Enhanced NMEA parser: extract numeric lat/lon/alt/speed/track
    - Convert NMEA coordinates to decimal degrees for GDL90 encoding
    - ESP32 creates "ForeFlight GPS" WiFi AP, sends GDL90 on UDP port 4000
    - ForeFlight auto-detects GPS data - no pairing or certification needed
    - OLED display updated to show WiFi connection status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
    [main.c]
2026-02-08 Clean up stale Bluetooth references and dead code
    Remove old Arduino sketch, update all config/docs to reflect
    WiFi/GDL90 implementation, add .gitignore.
2026-02-15 Enable WAAS/SBAS augmentation on M8N GPS module
    Adds UBX CFG-SBAS command to enable WAAS/SBAS correction signals, improving GPS accuracy from ~2.5m to ~1m. The module will now use satellite-based augmentation when available (WAAS in North America, EGNOS in Europe, MSAS in Asia).
    [main.c]
